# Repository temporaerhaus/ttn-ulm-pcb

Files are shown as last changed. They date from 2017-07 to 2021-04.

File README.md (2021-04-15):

# Münsterplatine – a pcb for LoRaWan

(Münsterplatine ist german for minster pcb.)

Welcome to the TTN Ulm Münsterplatine repository.
Our local TTN-community was under the impression that there is a tremendous need for a cheap and easy to use LoRaWan All-in-one kit, and so we created one.
The work is build around the ready-made arduino Pro Mini which can be bought from various sources for under 3 EUR per piece and the RFM96W LoRa tranceiver for communication.

After the board has been designed by the members of the community, we were sponsored by Initiative Ulm Digital that funded our initial production. 
Minsternode has then been prominently featured in many events, including the yearly conference of Initiave Ulm Digital and the event "Ulm Macht Zukunft".

# 2nd major version

(The most recent revision of this variant is v1.1)

In this version we added a multitude of goodies for you comfort as a LoRaWan-enthusiast. 
The features include:
* onboard FTDI and USB, so you can flash your Arduino easily by connecting it to your PC directly
* battery connector
* _battery charger_ included, so you can charge your LiPo-battery while plugged into the PC
* a combinded wire/ufl/sma connector is also onboard.
	
# 1st major version

This version aimed to satisfy you basic LoRaWan needs in form of a pcb on which the Arduino Pro Mini and the RMF95W-module can be soldered together. 
But beware: You still need a FTDI USB<->Serial converter to flash your Arduino. 
Since there is no additional hardware, this version is less energy-hungry than Version 2

You can find this version in the [legacy branch](https://github.com/verschwoerhaus/ttn-ulm-pcb/tree/legacy).

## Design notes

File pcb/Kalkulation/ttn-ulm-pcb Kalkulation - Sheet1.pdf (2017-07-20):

### Kostenaufstellung TTN-Ulm PCB

exkl. MwST | inkl. Mwst
Kosten pro Modul | €9.49 | €11.29 | Anzahl Module | 100
Kosten gesamt | €949.14 | €1,129.48
angepeilter Preis | 10€ | Zuschuss Ini ges | €129.48
Bauteil | Funktion | Kosten/1stk | Kosten/100stk | Anzahl pro Order | Kosten pro Order | # Bestellungen Link
FT232RL | USB - Serial | $1.63 | $162.80 | 10 | $16.28 | 10 https://www.aliexpress.com/item/Free-shipping-New-and-original-FT232RL-SSOP-28-FT232-10PCS/32640255274.html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,searchweb201602_3_10152_10065_10151_10068_10193_10194_10304_10137_10060_10302_10155_438_5360015_10154_10056_10055_10054_10059_100031_10099_10103_10102_10101_10052_10053_10142_10107_10050_10051_10084_10083_10080_10082_10081_10177_10110_10111_10112_10113_10114_10180_10182_10184_10078_10079_10073_10186_10189-10050,searchweb201603_5,ppcSwitch_7&btsid=def0bd48-6d92-40bc-b344-bb61ce6685d4&algo_expid=0a671695-9e7f-46da-b497-020b8f456faf-10&algo_pvid=0a671695-9e7f-46da-b497-020b8f456faf
MCP7381 | Ladecontroller | $0.10 | $9.90 | 100 | $9.90 | 1 https://www.aliexpress.com/item/5PCS-MCP73831T-2ACI-OT-SOT23-5-MCP73831T-2ACI-SOT-MCP73831T-MCP73831-SMD-free-shipping/32715288362.html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,searchweb201602_3_10152_10065_10151_10068_10193_10194_10304_10137_10060_10302_10155_438_5360015_10154_10056_10055_10054_10059_100031_10099_10103_10102_10101_10052_10053_10142_10107_10050_10051_10084_10083_10080_10082_10081_10177_10110_10111_10112_10113_10114_10180_10182_10184_10078_10079_10073_10186_10189,searchweb201603_5,ppcSwitch_7&btsid=b0ea11ee-4524-4873-92e8-d268ce4d3357&algo_expid=343263b7-23b0-40a5-98e1-150b7b8363d3-1&algo_pvid=343263b7-23b0-40a5-98e1-150b7b8363d3
SPX3819 | Spannungsregler | $0.12 | $11.55 | 100 | $11.55 | 1 https://www.aliexpress.com/item/50Pcs-SPX3819M5-3-3-SOT23-5-SPX3819-3-3-SOT23-SPX3819-SPX3819M5-SPX3819M5-3-3-TR/32718858136.html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,searchweb201602_3_10152_10065_10151_10068_10193_10194_10304_10137_10060_10302_10155_5360016_438_10154_10056_10055_10054_10059_100031_10099_10103_10102_10101_10052_10053_10142_10107_10050_10051_10084_10083_10080_10082_10081_10177_10110_10111_10112_10113_10114_10180_10182_10184_10078_10079_10073_10186_10189,searchweb201603_5,ppcSwitch_7&btsid=7c142f43-440d-4f4a-9ea0-74b5b3a2b845&algo_expid=491fc915-6b23-450e-adf0-75a3f7237dfb-0&algo_pvid=491fc915-6b23-450e-adf0-75a3f7237dfb
Arduino ProMini | $1.42 | $141.60 | 10 | $14.16 | 10 http://s.aliexpress.com/iYv2Ereq
RFM95W | LoRaWan | $6.00 | $600.00 | 1 | $6.00 | 100
Generic RLC | Kondensatoren/Widerstände... | $1.00 | $100.00 | 1 | $1.00 | 100
MicroUSB Buchse | $0.03 | $2.55 | 100 | $2.55 | 1 https://www.aliexpress.com/item/100pcs-micro-USB-socket-5pin-SMD-Pin-Long-needle-5pin-SMD-Copper-shell-Data-port-Charging/32649984667.html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,searchweb201602_3_10152_10065_10151_10068_10193_10194_10304_10137_10060_10302_10155_5360016_438_10154_10056_10055_10054_10059_100031_10099_10103_10102_10101_10052_10053_10142_10107_10050_10051_10084_10083_10080_10082_10081_10177_10110_10111_10112_10113_10114_10180_10182_10184_10078_10079_10073_10186_10189,searchweb201603_5,ppcSwitch_7&btsid=d2aa5840-d973-4581-80a7-cea12ea08b7d&algo_expid=ca4fadcc-fd46-48f5-a73f-febdd10fc253-1&algo_pvid=ca4fadcc-fd46-48f5-a73f-febdd10fc253
JST-J2-Buchse | Batterieanbindung | $0.08 | $7.98 | 50 | $3.99 | 2 https://www.aliexpress.com/item/20-Sets-Micro-JST-2-0-PH-2-Pin-Connector-plug-Male-Female-Crimps/32716138938.html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,searchweb201602_3_10152_10065_10151_10068_10193_10194_10304_10137_10060_10302_10155_5360016_438_10154_10056_10055_10054_10059_100031_10099_10103_10102_10101_10052_10053_10142_10107_10050_10051_10084_10083_10080_10082_10081_10177_10110_10111_10112_10113_10114_10180_10182_10184_10078_10079_10073_10186_10189,searchweb201603_5,ppcSwitch_7&btsid=16b90a85-7b1a-403c-ad3e-95b579ef08b3&algo_expid=02d22607-9ea2-44f5-9f54-28139aead7fe-10&algo_pvid=02d22607-9ea2-44f5-9f54-28139aead7fe
Platine | $0.52 | $52.00 | 100 | $52.00 | 1 http://dirtypcbs.com/store/pcbs

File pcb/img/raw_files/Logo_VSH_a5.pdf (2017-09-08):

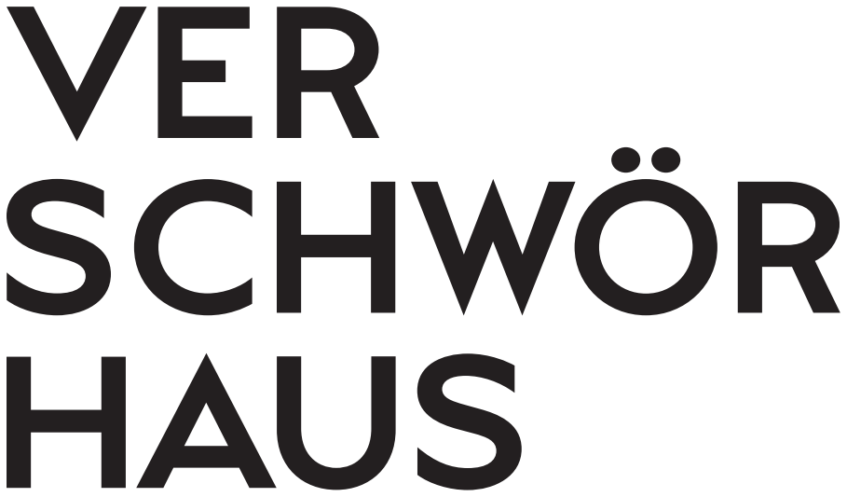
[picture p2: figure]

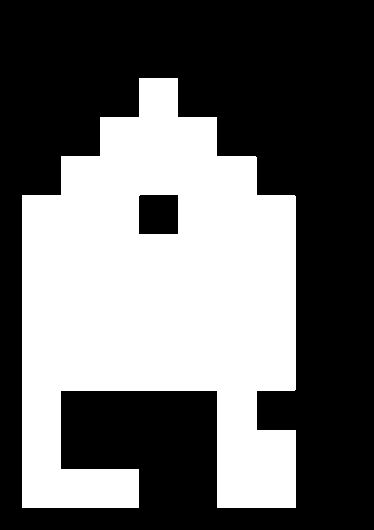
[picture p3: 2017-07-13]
pcb/img/raw_files/vsh.bmp

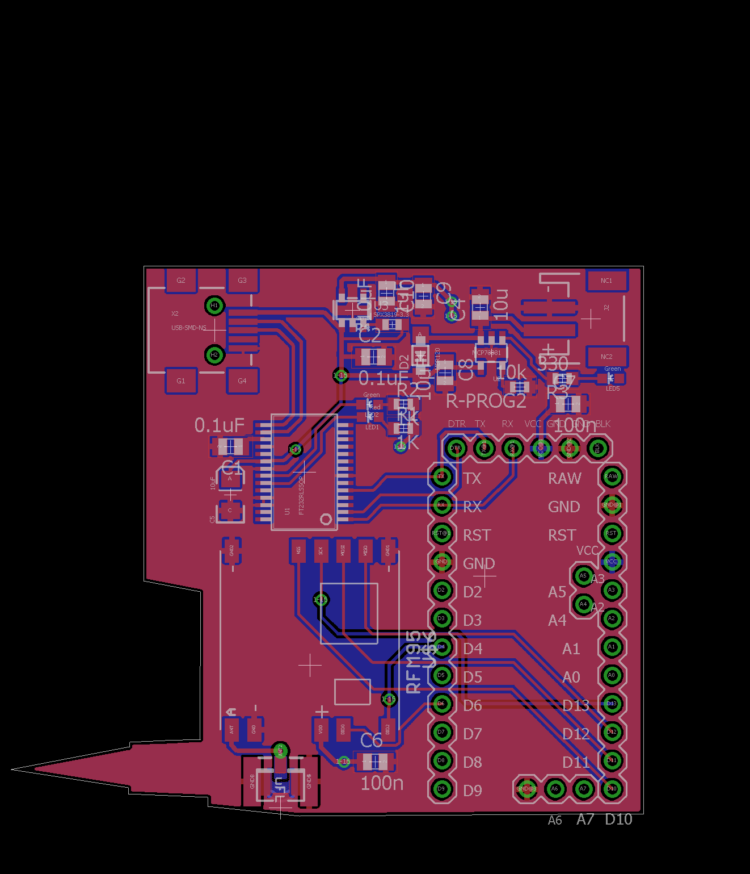
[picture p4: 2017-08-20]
pcb/img/raw_files/muensterform.png

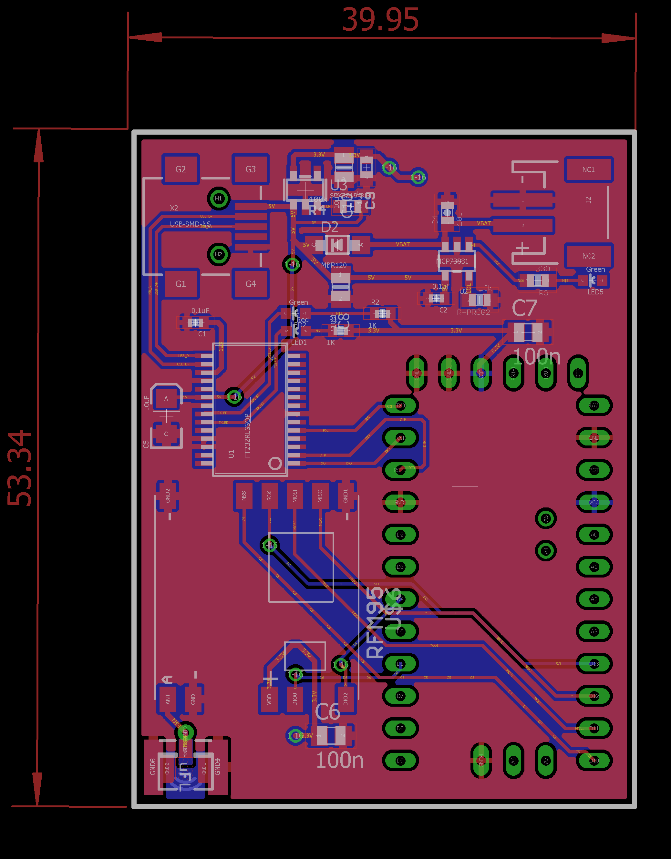
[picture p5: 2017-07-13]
pcb/img/raw_files/pcb.png

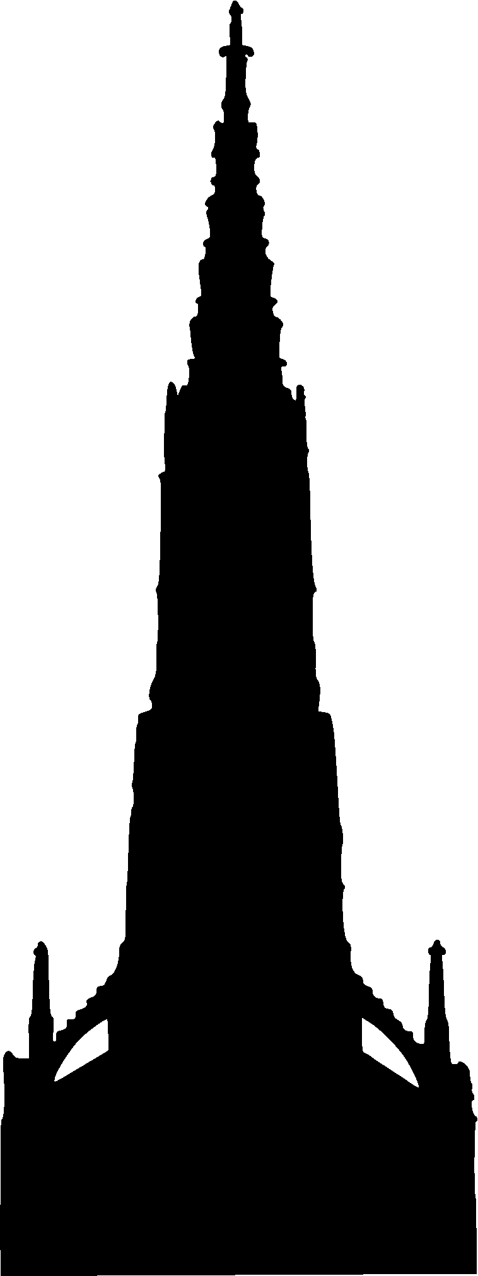
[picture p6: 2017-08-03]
pcb/img/raw_files/UlmerMünsterSilhouette.bmp

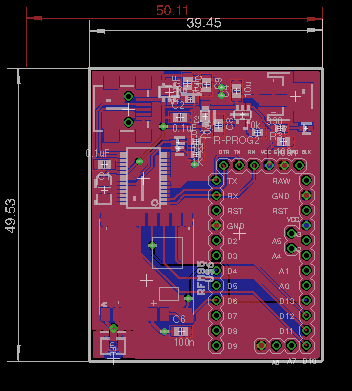
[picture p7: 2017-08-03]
pcb/img/raw_files/pcb_new.png

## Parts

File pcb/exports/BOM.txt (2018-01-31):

Stückliste exportiert aus /Users/deger/Desktop/git/ttn-ulm-pcb/Ulm PCB v2/projects/untitled.sch am 31.01.18 19:43

Part    Value       Device                Package          Description                                                                             PROD_ID   
C1      0.1uF       C-EUC0805             C0805            CAPACITOR, European symbol                                                                        
C2      0.1uF       C-EUC0805             C0805            CAPACITOR, European symbol                                                                        
C4      10u         C-EUC0805             C0805            CAPACITOR, European symbol                                                                        
C5      10uF        CAP_POL1206           EIA3216          Capacitor Polarized                                                                               
C6      100n        C-EUC0805             C0805            CAPACITOR, European symbol                                                                        
C7      100n        C-EUC0805             C0805            CAPACITOR, European symbol                                                                        
C8      10µF        C-EUC0805             C0805            CAPACITOR, European symbol                                                                        
C9      1uF         C-EUC0805             C0805            CAPACITOR, European symbol                                                                        
C10     10µF        C-EUC0805             C0805            CAPACITOR, European symbol                                                                        
D2      MBR120      DIODE-SCHOTTKYSOD-123 SOD-123                                                                                                            
                                                                           
J2                  JST_2MM_MALE          JST-2-SMD        Mates to single-cell LiPo batteries.                                                    CONN-08352
LED1    Red         LED0603               LED-0603         LEDs                                                                                              
LED2    Green       LED0603               LED-0603         LEDs                                                                                              
LED5    Green       LED0603               LED-0603         LEDs                                                                                              
R-PROG2 10k         R-EU_R0805            R0805            RESISTOR, European symbol                                                                         
R1      1K          R-EU_R0805            R0805            RESISTOR, European symbol                                                                         
R2      1K          R-EU_R0805            R0805            RESISTOR, European symbol                                                                         
R3      330         R-EU_R0805            R0805            RESISTOR, European symbol                                                                         
R4      100k        RESISTOR_0603_NOOUT   0603-NO          Resistors                                                                                         
                                                            
U1      FT232RLSSOP FT232RLSSOP           SSOP28DB         USB UART                                                                                          
U2      MCP73831    MCP73831              SOT23-5          Miniature single cell, fully integrated Li-Ion, Li-polymer charge management controller IC-09995  
U3      SPX3819-3.3 VREG_SOT23-5          SOT23-5          SOT23-5 Fixed Voltage Regulators                                                                  
                                                             
X3      microUSB    USB_MICRO_20329_V2    4UCONN_20329_V2  USB Connectors

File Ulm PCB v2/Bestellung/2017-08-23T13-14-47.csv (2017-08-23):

Index | Menge | Teilenummer | Beschreibung | Kundenreferenz | Verfügbare Menge | Nachbestellmenge | Einheitspreis EUR | Gesamtpreis
EUR
1 | 10 | MCP73831T-2ACI/OTCT-ND | IC CONTROLLR LI-ION 4.2V SOT23-5 |  | 10 | 0 | 0 | 49000 | 4 | 90
2 | 10 | 768-1007-1-ND | IC USB FS SERIAL UART 28-SSOP |  | 10 | 0 | 3 | 43800 | 34 | 38
3 | 10 | 1016-1873-1-ND | IC REG LINEAR 3.3V 500MA SOT23-5 |  | 10 | 0 | 0 | 53600 | 5 | 36
4 | 10 | 609-4616-1-ND | CONN USB MICRO B RECPT SMT R/A |  | 10 | 0 | 0 | 37100 | 3 | 71
5 | 10 | 455-1564-1-ND | CONN HEADER GH SIDE 2POS 1.25MM |  | 10 | 0 | 0 | 37200 | 3 | 72
6 | 120 | 160-1446-6-ND | LED GREEN CLEAR 0603 SMD |  | 120 | 0 | 0 | 14642 | 17 | 57
7 | 120 | 160-1445-1-ND | LED ORANGE CLEAR 0603 SMD |  | 120 | 0 | 0 | 08780 | 10 | 54
8 | 120 | 160-1447-1-ND | LED RED CLEAR 0603 SMD |  | 120 | 0 | 0 | 09430 | 11 | 32
9 | 5000 | RMCF0805JT330RTR-ND | RES SMD 330 OHM 5% 1/8W 0805 |  | 5000 | 0 | 0 | 00185 | 9 | 23
10 | 5000 | 311-1.0KARTR-ND | RES SMD 1K OHM 5% 1/8W 0805 |  | 5000 | 0 | 0 | 00208 | 10 | 39
11 | 5000 | 311-100KCRTR-ND | RES SMD 100K OHM 1% 1/8W 0805 |  | 5000 | 0 | 0 | 00241 | 12 | 05
12 | 10000 | 478-1129-2-ND | CAP CER 0.1UF 10V X5R 0402 |  | 10000 | 0 | 0 | 00153 | 15 | 30
13 | 3000 | 490-1718-2-ND | CAP CER 10UF 6.3V X5R 0805 |  | 3000 | 0 | 0 | 03358 | 100 | 73
14 | 3000 | 311-1365-2-ND | CAP CER 1UF 16V X7R 0805 |  | 3000 | 0 | 0 | 01328 | 39 | 83
15 | 100 | MBR120VLSFT3GOSCT-ND | DIODE SCHOTTKY 20V 1A SOD123FL |  | 100 | 0 | 0 | 18500 | 18 | 50

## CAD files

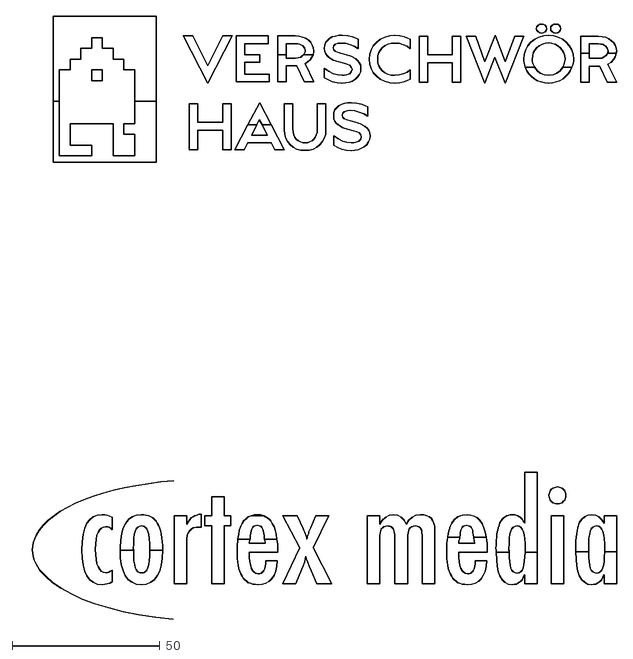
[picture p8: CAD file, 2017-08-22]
pcb/img/raw_files/logos_v2_export_test2.dxf
203.5 x 204.3

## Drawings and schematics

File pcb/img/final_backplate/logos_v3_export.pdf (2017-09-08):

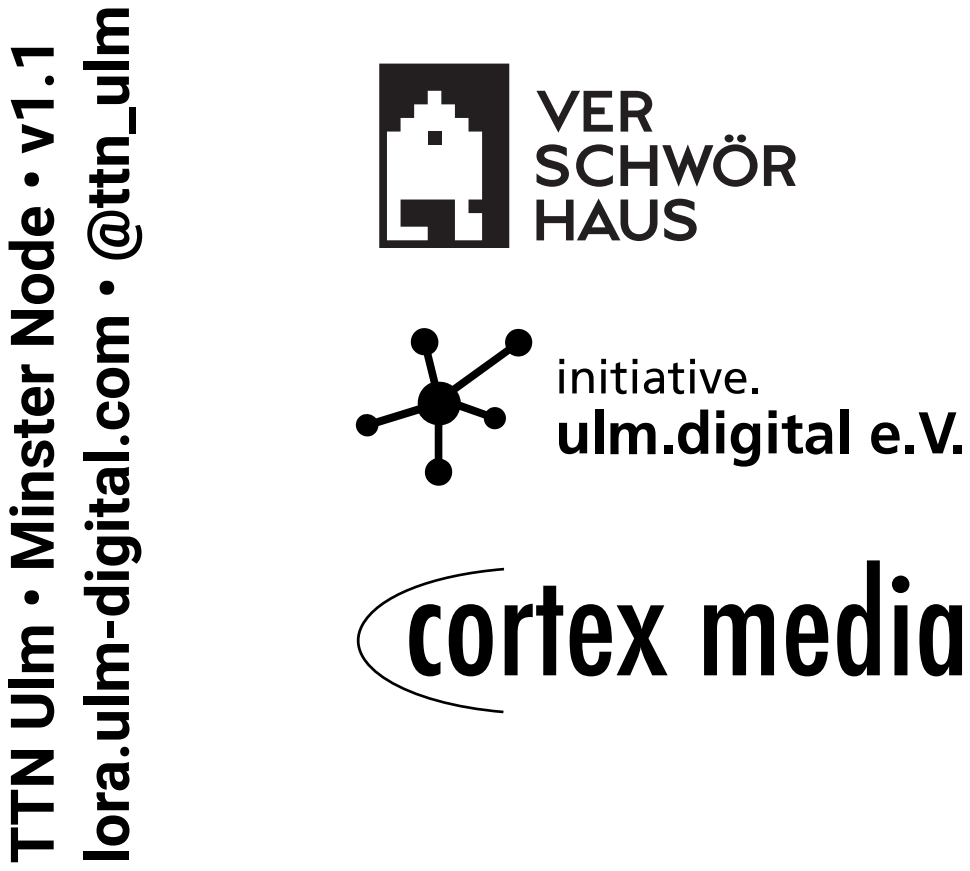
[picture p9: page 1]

TTN Ulm • Minster Node • v1.1

lora.ulm-digital.com • @ttn_ulm

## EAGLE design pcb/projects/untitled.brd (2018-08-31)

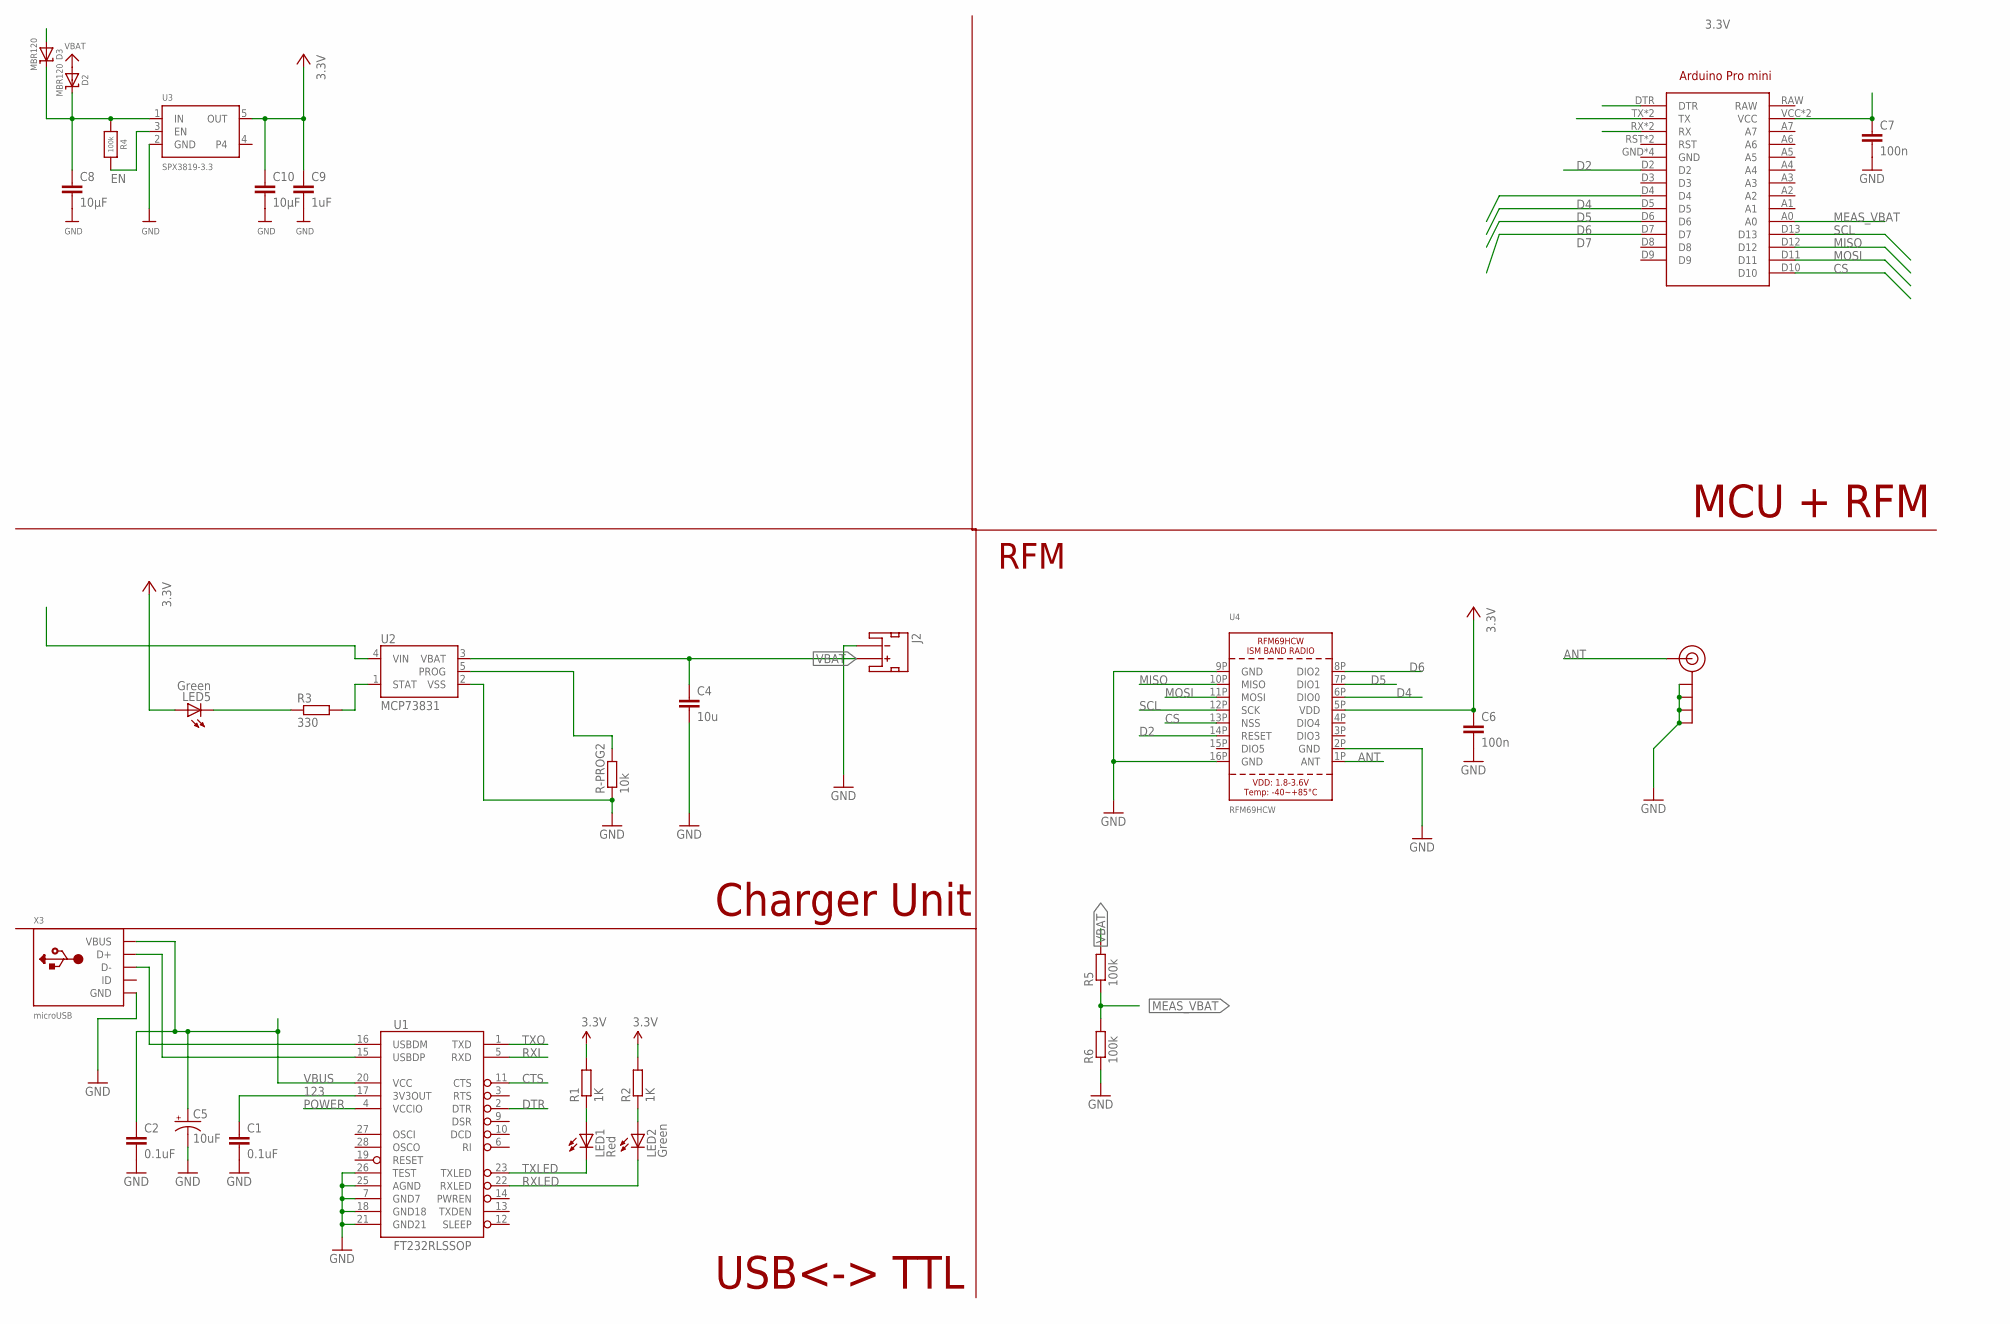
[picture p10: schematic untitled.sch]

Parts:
C1, C2: 0.1uF; C0805
C4: 10u; C0805
C5: 10uF; EIA3216
C6, C7: 100n; C0805
C8, C10: 10µF; C0805
C9: 1uF; C0805
D2, D3: MBR120; SOD-123
J2: JST_2MM_MALE; JST-2-SMD
J$2: ANTENNATINY; SMA_UFL_PAD_TINY
LED1: Red; LED-0603
LED2, LED5: Green; LED-0603
R1, R2: 1K; R0805
R3: 330; R0805
R4: 100k; 0603-NO
R5, R6: 100k; R0805
R-PROG2: 10k; R0805
U1: FT232RLSSOP; SSOP28DB
U2: MCP73831; SOT23-5
U3: SPX3819-3.3; SOT23-5
U4: RFM69HCW; RFMHCW_SMT
U$1: ARDUINO_PRO_MINI
X3: microUSB; 4UCONN_20329_V2

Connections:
3.3V: C6.1, C7.1, C9.1, C10.1, LED5.A, R1.2, R2.2, U3.5 (OUT), U4.5P (VDD), U$1.VCC, U$1.VCC@1 (VCC)
123: C1.1, U1.17 (3V3OUT)
ANT: J$2.ANT1 (SIGNAL), J$2.ANT2 (SIGNAL), J$2.ANT3 (SIGNAL), U4.1P (ANT)
CS: U4.13P (NSS), U$1.D10
CTS: U1.11 (CTS)
D2: U4.14P (RESET), U$1.D2
D4: U4.6P (DIO0), U$1.D4
D5: U4.7P (DIO1), U$1.D5
D6: U4.8P (DIO2), U$1.D6
D7: U$1.D7
DTR: U1.2 (DTR), U$1.DTR
EN: R4.2, U3.3 (EN)
GND: C1.2, C2.2, C4.2, C5.C (-), C6.2, C7.2, C8.2, C9.2, C10.2, J2.1 (-), J$2.GND1 (GND), J$2.GND2 (GND), J$2.GND3 (GND), J$2.GND4 (GND), R6.1, R-PROG2.1, U1.7 (GND7), U1.18 (GND18), U1.21 (GND21), U1.25 (AGND), U1.26 (TEST), U2.2 (VSS), U3.2 (GND), U4.2P (GND), U4.9P (GND), U4.16P (GND), U$1.GND, U$1.GND@1 (GND), U$1.GND@2 (GND), U$1.GND@3 (GND), X3.BASE@1 (GND), X3.BASE@2 (GND), X3.GND, X3.SPRT@1 (GND), X3.SPRT@2 (GND), X3.SPRT@3 (GND), X3.SPRT@4 (GND)
LOL: R-PROG2.2, U2.5 (PROG)
MEAS_VBAT: R5.1, R6.2, U$1.A0
MISO: U4.10P (MISO), U$1.D12
MOSI: U4.11P (MOSI), U$1.D11
unnamed: LED1.A, R1.1
unnamed: LED2.A, R2.1
unnamed: LED5.C, R3.1
unnamed: R3.2, U2.1 (STAT)
POWER: U1.4 (VCCIO)
RXI: U1.5 (RXD), U$1.TX, U$1.TX@1 (TX)
RXLED: LED2.C, U1.22 (RXLED)
SCL: U4.12P (SCK), U$1.D13
TXLED: LED1.C, U1.23 (TXLED)
TXO: U1.1 (TXD), U$1.RX, U$1.RX@1 (RX)
USB_D+: U1.15 (USBDP), X3.D+
USB_D-: U1.16 (USBDM), X3.D-
V5: C8.1, D2.C, D3.C, R4.1, U2.4 (VIN), U3.1 (IN)
VBAT: C4.1, D2.A, J2.2 (+), R5.2, U2.3 (VBAT)
VBUS: C2.1, C5.A (+), D3.A, U1.20 (VCC), X3.VBUS

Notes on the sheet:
USB<-> TTL
Charger Unit
MCU + RFM
RFM

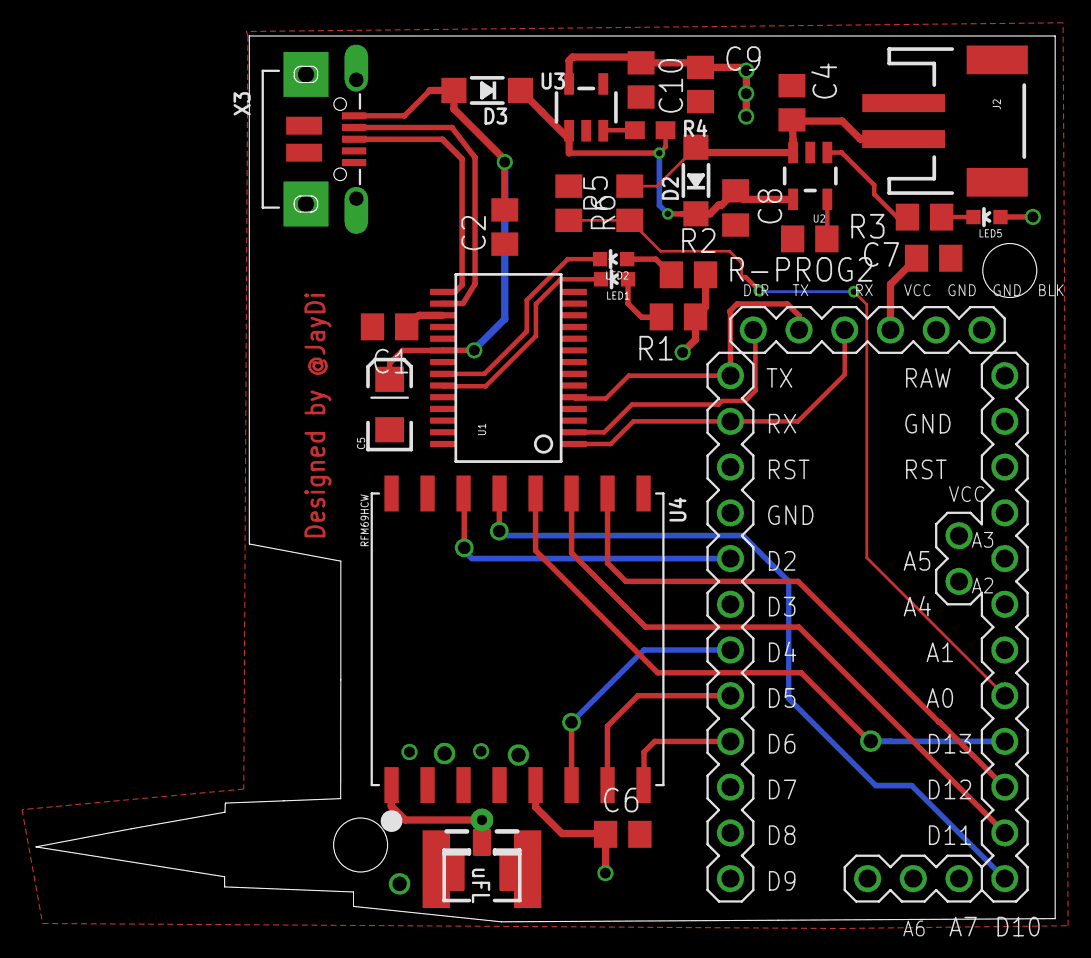
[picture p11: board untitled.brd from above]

Board: 2 copper layers, 56.6 x 49.2 mm, 29 parts (0 on the bottom side), 29 nets.

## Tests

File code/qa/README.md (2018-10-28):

_Dieses Dokument ist in Englisch verfasst, da es Informationen für Fortgeschrittene enthält._

# Some Quality Assurance

As our boards are botched up, i.e. produced manually, we'll also call it _botch assurance_.

## General Information

arduino-cli (still beta)
* https://blog.arduino.cc/2018/08/24/announcing-the-arduino-command-line-interface-cli/
* https://github.com/arduino/arduino-cli

RaspberryPi:
* If you are going to build arduino-cli yourself (go) you probably need a Pi with 1 GB of RAM.

## Setup

Raspberry Pi image: Raspbian Stretch Lite
```
Raspbian Stretch Lite
Minimal image based on Debian Stretch
Version: October 2018
Release date: 2018-10-09
Kernel version: 4.14
```

`raspi-config`:
* change password
* change hostname (N1) -> {{{ttnulm-ba}}}; ba is fpr botch assurance ;-)
* predictable network interface (N3) -> enable
* locale -> e.g. de_DE.UTF-8 UTF-8
* change keyboard layout
* activate SSH (P2)
* expand filesystem (A1)

If you want to, now is the time to access the pi via SSH:
```
ssh pi@ttnulm-ba.lan
# or:
ssh pi@ttnulmba.local
```

Install packages:
```
sudo apt install byobu
byobu
sudo apt update; sudo apt full-upgrade
sudo apt install vim git python3-pip python3-gpiozero
```

arduino-cli:
```
mkdir -p ~/ba/tmp
cd ~/ba/tmp
wget https://downloads.arduino.cc/arduino-cli/arduino-cli-0.3.1-alpha.preview-linuxarm.tar.bz2
tar xvjf arduino-cli-0.3.1-alpha.preview-linuxarm.tar.bz2
sudo mv arduino-cli-0.3.1-alpha.preview-linuxarm /usr/local/bin/arduino-cli

# we'll need the arduino:avr cores and the LMIC 1.5 library
arduino-cli core update-index
arduino-cli core install arduino:avr
arduino-cli lib install "IBM LMIC framework"
```

## Actual BA

```
mkdir -p ~/ba
cd ~/ba
```

### TTN

* Create app and device.
* Set activation method to ABP and **disable frame counter checks**.

### Arduino

THE BA IS STILL WORK IN PROGRESS, SO THE FOLLOWING PART OF THIS DOCUMENTATION IS NOT FINISHED YET.

Download testing routines, compile and flash:
```
mkdir ...
cd ...
wget ....

cd ..

arduino-cli compile --fqbn arduino:avr:pro:cpu=8MHzatmega328 muenster_hello_world
arduino-cli upload --port /dev/ttyUSB0 --fqbn arduino:avr:pro:cpu=8MHzatmega328 muenster_hello_world
```

### Debugging

`arduino-cli board list` should return:
```
FQBN    Port            ID              Board Name
        /dev/ttyUSB0    0403:6001       unknown
```

arduino-cli can not find the board try `lsusb` which should return:
```
Bus 001 Device 004: ID 0403:6001 Future Technology Devices International, Ltd FT232 USB-Serial (UART) IC
```

# Surplus information

_Not needed for BA._

arduino-cli build with go:
```
sudo apt install snapd
sudo reboot

sudo snap install go --classic
go get -u github.com/arduino/arduino-cli
sudo cp /home/pi/go/bin/arduino-cli /usr/local/bin/arduino-cli
```

Arduino IDE (not necessary):
```
wget https://downloads.arduino.cc/arduino-1.8.7-r1-linuxarm.tar.xz
tar xvJf arduino-1.8.7-r1-linuxarm.tar.xz
cd arduino-1.8.7
./arduino-linux-setup.sh pi
sudo reboot
```

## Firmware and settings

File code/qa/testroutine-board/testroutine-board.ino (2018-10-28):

/***********************************************************************

Hello World für die Münsterplatine (TTN Ulm)
============================================

Einfaches Beispiel für die Übertragung der ersten LoRaWAN-Pakete. Dafür
muss nur der mit TODO markierte Block angepasst werden.

Mehr zu TTN und der Platine unter:
https://lora.ulm-digital.com/documentation/minster-node

***********************************************************************/


#include <lmic.h>
#include <hal/hal.h>
#include <SPI.h>


/* TODO TTN-Anmeldedaten für das Device eintragen
**************************************************/

// applications/ttn_ulm-muenstertest/devices/botch-assurance-001
static const PROGMEM u1_t NWKSKEY[16] = { 0x92, 0x41, 0xE9, 0x92, 0x07, 0x10, 0xD7, 0xA1, 0x34, 0x2A, 0x4B, 0x84, 0x5B, 0x1D, 0xE1, 0x32 };
static const u1_t PROGMEM APPSKEY[16] = { 0x67, 0x44, 0x4B, 0xF7, 0x7B, 0x75, 0xD2, 0x64, 0x4D, 0x9A, 0x00, 0x7D, 0x75, 0x38, 0xA3, 0x01 };
static const u4_t DEVADDR = 0x26011522;

// applications/ttn_ulm-muenstertest/devices/simon-001b
//static const PROGMEM u1_t NWKSKEY[16] = { 0x89, 0x75, 0xAB, 0x04, 0xFD, 0xA3, 0x7E, 0xF9, 0xAD, 0x6F, 0xD6, 0x41, 0x70, 0x39, 0x5E, 0x60 };
//static const u1_t PROGMEM APPSKEY[16] = { 0xA9, 0xD9, 0xF7, 0xD2, 0xC4, 0xD5, 0xFB, 0x37, 0xB4, 0xC2, 0x60, 0x81, 0xB3, 0x63, 0x35, 0x04 };
//static const u4_t DEVADDR = 0x26011591;

// Das sieht dann ungefähr so aus:
//static const PROGMEM u1_t NWKSKEY[16] = { 0x1B, 0x1B, 0xF8, 0x14, 0x3B, 0x77, 0x26, 0x58, 0xF3, 0x88, 0x4E, 0x1C, 0xB1, 0xAB, 0x04, 0xGC };
//static const u1_t PROGMEM APPSKEY[16] = { 0xD1, 0xC3, 0xB9, 0x23, 0xF4, 0x65, 0x0A, 0x9A, 0x24, 0x90, 0x0A, 0x14, 0xA9, 0x8F, 0x1F, 0xA1 };
//static const u4_t DEVADDR = 0x26011F9I;



/* Sonstige Einstellungen
**************************/

// Sendeintervall:
const unsigned TX_INTERVAL = 30;

// Datenrate bzw. spreading factor:
#define dataRate DR_SF7
// Sendeleistung:
int txPower = 14;

// Pin-Zuordung für LoRa-Modul (RFM95):
const lmic_pinmap lmic_pins = {
        .nss = 10,                // TTN Ulm Münsterplatine: 10
        .rxtx = LMIC_UNUSED_PIN,
        .rst = LMIC_UNUSED_PIN,
        .dio = {4, 5, 6},         // TTN Ulm Münsterplatinge: {4, 5 ,6}
};



void os_getArtEui (u1_t* buf) { }
void os_getDevEui (u1_t* buf) { }
void os_getDevKey (u1_t* buf) { }

static osjob_t sendjob;

void onEvent (ev_t ev) {
    Serial.print(os_getTime());
    Serial.print(": ");
    switch(ev) {
        case EV_SCAN_TIMEOUT:
            Serial.println(F("EV_SCAN_TIMEOUT"));
            break;
        case EV_BEACON_FOUND:
            Serial.println(F("EV_BEACON_FOUND"));
            break;
        case EV_BEACON_MISSED:
            Serial.println(F("EV_BEACON_MISSED"));
            break;
        case EV_BEACON_TRACKED:
            Serial.println(F("EV_BEACON_TRACKED"));
            break;
        case EV_JOINING:
            Serial.println(F("EV_JOINING"));
            break;
        case EV_JOINED:
            Serial.println(F("EV_JOINED"));
            break;
        case EV_RFU1:
            Serial.println(F("EV_RFU1"));
            break;
        case EV_JOIN_FAILED:
            Serial.println(F("EV_JOIN_FAILED"));
            break;
        case EV_REJOIN_FAILED:
            Serial.println(F("EV_REJOIN_FAILED"));
            break;
        case EV_TXCOMPLETE:
            Serial.println(F("EV_TXCOMPLETE (includes waiting for RX windows)"));
            if (LMIC.txrxFlags & TXRX_ACK)
                Serial.println(F("Received ack"));
            if (LMIC.dataLen) {
                Serial.println(F("Received "));
                Serial.println(LMIC.dataLen);
                Serial.println(F(" bytes of payload"));
            }
            // Schedule next transmission
            os_setTimedCallback(&sendjob, os_getTime()+sec2osticks(TX_INTERVAL), do_send);
            break;
        case EV_LOST_TSYNC:
            Serial.println(F("EV_LOST_TSYNC"));
            break;
        case EV_RESET:
            Serial.println(F("EV_RESET"));
            break;
        case EV_RXCOMPLETE:
            // data received in ping slot
            Serial.println(F("EV_RXCOMPLETE"));
            break;
        case EV_LINK_DEAD:
            Serial.println(F("EV_LINK_DEAD"));
            break;
        case EV_LINK_ALIVE:
            Serial.println(F("EV_LINK_ALIVE"));
            break;
        default:
            Serial.println(F("Unknown event"));
            break;
    }
}

void do_send(osjob_t* j){
    // Check if there is not a current TX/RX job running
    if (LMIC.opmode & OP_TXRXPEND) {
        Serial.println(F("OP_TXRXPEND, not sending"));
    } else {

        int aNumber = 16153;            // Höhe des Ulmer Münsters in cm.
                                        // 16153 entspricht 3F19 in hexadezimaler Darstellung

        byte payload[2];
        payload[0] = highByte(aNumber);
        payload[1] = lowByte(aNumber);

        LMIC_setTxData2(1, (uint8_t*)payload, sizeof(payload), 0);

        Serial.println(F("Packet queued"));
    }
}

void setup() {
    Serial.begin(9600);
    Serial.println(F("Starting"));

#ifdef VCC_ENABLE
    // For Pinoccio Scout boards
    pinMode(VCC_ENABLE, OUTPUT);
    digitalWrite(VCC_ENABLE, HIGH);
    delay(1000);
#endif

    // LMIC init
    os_init();
    // Reset the MAC state. Session and pending data transfers will be discarded.
    LMIC_reset();

#ifdef PROGMEM
    uint8_t appskey[sizeof(APPSKEY)];
    uint8_t nwkskey[sizeof(NWKSKEY)];
    memcpy_P(appskey, APPSKEY, sizeof(APPSKEY));
    memcpy_P(nwkskey, NWKSKEY, sizeof(NWKSKEY));
    LMIC_setSession (0x1, DEVADDR, nwkskey, appskey);
#else
    // If not running an AVR with PROGMEM, just use the arrays directly
    LMIC_setSession (0x1, DEVADDR, NWKSKEY, APPSKEY);
#endif

#if defined(CFG_eu868)
    LMIC_setupChannel(0, 868100000, DR_RANGE_MAP(DR_SF12, DR_SF7),  BAND_CENTI);      // g-band
    LMIC_setupChannel(1, 868300000, DR_RANGE_MAP(DR_SF12, DR_SF7B), BAND_CENTI);      // g-band
    LMIC_setupChannel(2, 868500000, DR_RANGE_MAP(DR_SF12, DR_SF7),  BAND_CENTI);      // g-band
    LMIC_setupChannel(3, 867100000, DR_RANGE_MAP(DR_SF12, DR_SF7),  BAND_CENTI);      // g-band
    LMIC_setupChannel(4, 867300000, DR_RANGE_MAP(DR_SF12, DR_SF7),  BAND_CENTI);      // g-band
    LMIC_setupChannel(5, 867500000, DR_RANGE_MAP(DR_SF12, DR_SF7),  BAND_CENTI);      // g-band
    LMIC_setupChannel(6, 867700000, DR_RANGE_MAP(DR_SF12, DR_SF7),  BAND_CENTI);      // g-band
    LMIC_setupChannel(7, 867900000, DR_RANGE_MAP(DR_SF12, DR_SF7),  BAND_CENTI);      // g-band
    LMIC_setupChannel(8, 868800000, DR_RANGE_MAP(DR_FSK,  DR_FSK),  BAND_MILLI);      // g2-band
#elif defined(CFG_us915)
    LMIC_selectSubBand(1);
#endif

    // Disable link check validation
    LMIC_setLinkCheckMode(0);

    // TTN uses SF9 for its RX2 window.
    LMIC.dn2Dr = DR_SF9;

    // Set data rate and transmit power for uplink (note: txpow seems to be ignored by the library)
    LMIC_setDrTxpow(dataRate, txPower);

    // Start job
    do_send(&sendjob);
}

void loop() {
    os_runloop_once();
}

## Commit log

2017-07-06 initital commit
    [panel.kicad_pcb, ttnulm.kicad_pcb, ttnulm.sch]
2017-07-11 Version 2 hinzugefügt. Todo: * Add Voltage Regulator (wire up) * Add other ProMini-Designs * Credits
    [untitled.brd, untitled.sch]
2017-07-11 connected \!DTR Pin to RST
    [untitled.brd, untitled.sch]
2017-07-13 reworked layout. Added voltage controller and discharging mechanism
    [untitled.brd, untitled.sch]
2017-07-13 prinzipiell Produktionsreif. Todo: Verkürzen
    [untitled.brd]
2017-07-13 Technische Arbeiten abgeschlossen. Logo fehlt noch
    [untitled.brd]
2017-07-13 refactored file structure, updated README
    [panel.kicad_pcb, ttnulm.kicad_pcb, ttnulm.sch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]
2017-07-13 rerouted rmf power suppyl
    [untitled.brd]
2017-07-13 rerouted arduino power suppyl
    [untitled.brd]
2017-07-13 nicing of batterycharger
    [untitled.brd]
2017-07-16 WIP: reducing height. Antenna must be refitted
    [untitled.brd]
2017-07-16 Board now approx 5x4 cm
    [untitled.brd, untitled.sch]
2017-07-16 Successful designrule check
    [untitled.brd]
2017-07-16 corrected gnd path to FT232RL
    [untitled.brd]
2017-07-16 corrected one polygon. made antenna trace shorter
    [untitled.brd]
2017-07-20 replaced some parts with their bigger equivalent
    [untitled.brd, untitled.sch]
2017-07-20 updated calc sheets with arduino pro mini 328p. Kudos to Simon Fuchs
2017-07-31 richtiges Arduino Pro Mini Pinout hinzugefügt
2017-07-31 nicing of some traces
    [untitled.brd, untitled.sch]
2017-08-03 rerouted traces to make room for the big M ( =muenster)
    [untitled.brd]
2017-08-03 added picture of board layout
    [untitled.brd, untitled.dxf]
2017-08-03 Revert "added picture of board layout"
    This reverts commit 6c2dd7b23edb37982c4fb7cb2418e2451a8ef545.
    [untitled.brd, untitled.dxf]
2017-08-03 added new board layout
    [untitled.brd]
2017-08-20 Deployed Münsterdesign
    [untitled.brd]
2017-08-21 replaced some of the 0603 Resistors with 0805
    [untitled.brd, untitled.sch]
2017-08-22 Added remaining Logos on backside silkscreen
    [logos_v2_export_test2.dxf, untitled.brd]
2017-08-22 corrected one DRC-Error
    [untitled.brd]
2017-08-23 moved logos slightly. Tried correcting muenster's imbalance
    [untitled.brd]
2017-08-23 Finalized design
    [untitled.brd, untitled.sch]
2017-08-23 added order information
    [2017-08-23T12-49-11.csv]
2017-08-23 updated order list
    [2017-08-23T13-14-47.csv]
2017-08-23 Last time: updated Orderlist
    [2017-08-23T13-29-48.csv]
2017-08-23 added panelized gerber files
    [combined.GKO, combined.gbl, combined.gbo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]
2017-09-08 added v3 of backplate logos
    [logos_v2_export_test2.dxf]
2017-09-13 Fixed Bug regarding Pinout of RFM95W
    [untitled.brd, untitled.sch]
2017-09-13 Added new back panel logos
    [untitled.brd]
2017-09-13 corrected DRC-Errors. ToDo: Right USB Slot, Diode vs. Jumper
    [untitled.brd, untitled.sch]
2017-09-13 Final Final
    [untitled.brd, untitled.sch]
2017-09-13 Gerber Files v2
    [untitled.GBL, untitled.GBO, untitled.GBP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]
2017-09-14 added new panelized gerber files
    [combined.GKO, combined.gbl, combined.gbo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]
2017-09-14 Fixed Cap. Values for better voltage stabilazation
    [untitled.brd, untitled.sch]
2017-09-22 added microUSB
    [untitled.brd, untitled.sch]
2017-09-24 Added Cam-Job. Gerber Gerber Gerber
    [untitled.GBL, untitled.GBO, untitled.GBP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]
2018-01-31 Updated Design. Fixed last bugs. Updated BOM
2018-01-31 Updated BOM
2018-06-13 added battery voltage monitoring
    [untitled.brd, untitled.sch]
2018-08-31 Generated Gerber-files for enhanced pcb-layout
    [untitled.GBL, untitled.GBO, untitled.GBP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]
2018-10-28 Refactored directory structure. Added some screenshots for the sake of docu
    [2017-08-23T13-29-48.csv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]

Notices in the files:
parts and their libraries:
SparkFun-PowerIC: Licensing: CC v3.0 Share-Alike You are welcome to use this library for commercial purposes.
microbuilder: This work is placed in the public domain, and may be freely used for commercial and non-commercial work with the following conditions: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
